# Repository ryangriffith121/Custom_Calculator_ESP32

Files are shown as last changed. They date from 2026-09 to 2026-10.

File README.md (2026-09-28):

# Custom Calculator ESP32

A custom calculator project built around an ESP32 microcontroller and a 4-inch ST7796S TFT display. The PCB and schematic have been developed in KiCad, and the next phase is generating Gerber files for manufacturing, followed by enclosure design and firmware development.

## 🎯 Project Goal

Create a compact, custom 4-function calculator with:

- Addition
- Subtraction
- Multiplication
- Division

The design combines a tactile keypad matrix, a high-visibility graphics display, and a lightweight ESP32-based control system.

## 🧩 Hardware Overview

### Core controller
- ESP32 development module / ESP32-WROOM-style board footprint
- Connected to the keypad matrix and display interface
- Planned for calculation logic, UI rendering, and input handling

### Display
- 4-inch TFT display
- ST7796S controller
- Intended for calculator UI, numeric input, operator selection, and result display

### Input device
- Tactile switch matrix arranged in a key layout
- Supports numeric keys and operator keys
- Wiring is organized in a row/column matrix for efficient GPIO usage

### Power and support
- 3.3V logic rail
- Test points for power, reset, SPI, and signal debug
- ESP32 GPIOs mapped for display and keypad interfacing

## ✅ Current Status

### Completed
- PCB design completed in KiCad
- Schematic capture completed in KiCad
- Gerber files generated and ready for manufacturing
- Device planning for ESP32 + display + keypad matrix
- GPIO and pin allocation for the external interfaces
- Basic project structure in the workspace

Schematic:


PCB Layout and Wiring:



PCB Rendering:



### Remaining work
- Enclosure design and mechanical fit for the display, buttons, and assembly
- Firmware programming for keypad scanning, display output, and calculator logic
- Final validation and hardware bring-up

## 📁 Repository Structure

```text
Custom_Calculator_ESP32/
├── CAD/
│   └── (mechanical / enclosure or enclosure-related files)
├── ECAD/
│   └── Calculator/
│       ├── Calculator.kicad_pro
│       ├── Calculator.kicad_sch
│       ├── Calculator.kicad_pcb
│       └── Calculator.kicad_prl
├── Programming/
│   └── (firmware source code and future development files)
├── README.md
└── .git/
```

## 📝 Design Notes

This project is intended to be a functional calculator rather than a general-purpose embedded display demo. The hardware is being designed around a straightforward architecture:

1. User presses keypad buttons.
2. ESP32 reads the matrix input.
3. Firmware interprets numeric and operator inputs.
4. Calculation result is rendered on the ST7796S display.

## 🚀 Planned Next Steps

- Design the enclosure to match the completed PCB and display layout
- Add silkscreen labeling and mechanical constraints
- Complete firmware programming for keypad scanning, display rendering, and calculator logic
- Validate the display graphics and UI flow on the physical hardware
- Finalize assembly and testing of the completed calculator

## 💻 Firmware Direction

The firmware can be implemented with:

- GPIO scanning for the keypad matrix
- SPI communication to the ST7796S TFT display
- Basic arithmetic state machine for calculator operation
- Keyboard debounce handling
- Result and expression rendering on screen

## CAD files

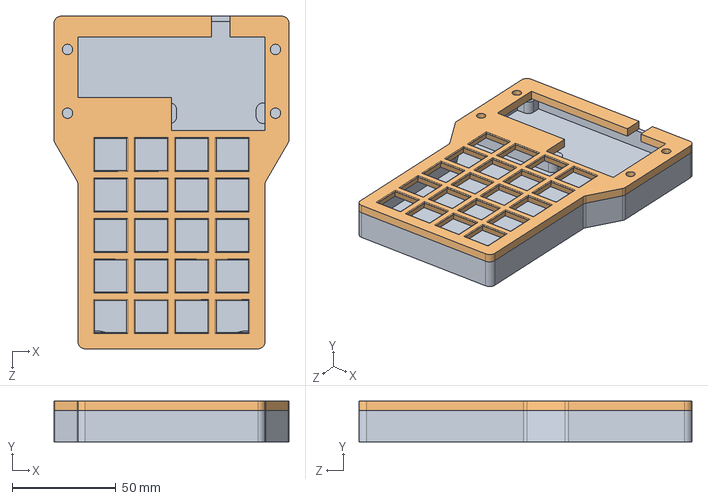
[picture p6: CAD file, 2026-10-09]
CAD/Calculator_Assem.STEP
113.0 x 19.5 x 160.0 mm
Calculator_Body_V2
Calculator_Plate

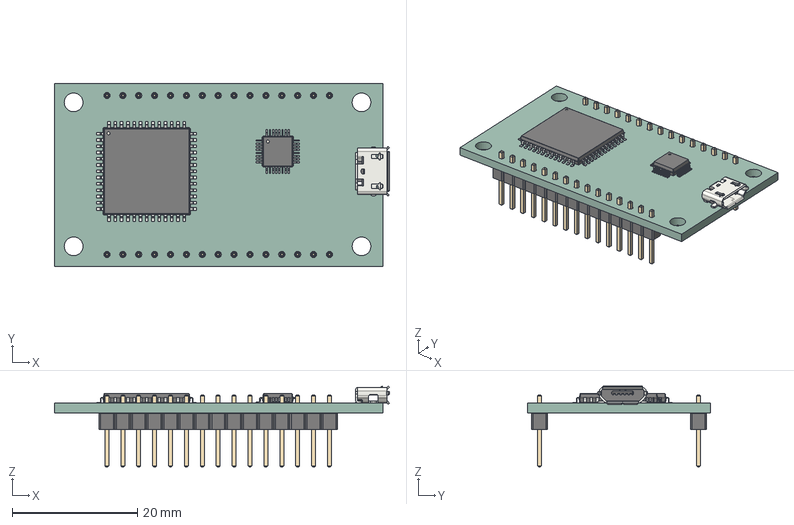
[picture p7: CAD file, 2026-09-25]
ECAD/Calculator/lib_models/ESP32-30pin.step
53.5 x 29.2 x 12.9 mm
LQFP_52_14x14mm_P1mm
USB_Micro-B_Molex_47346-0001
LQFP_32_5x5mm_P05mm
PinHeader_1x15_P254mm_Vertical x 2
ESP32-30pin PCB

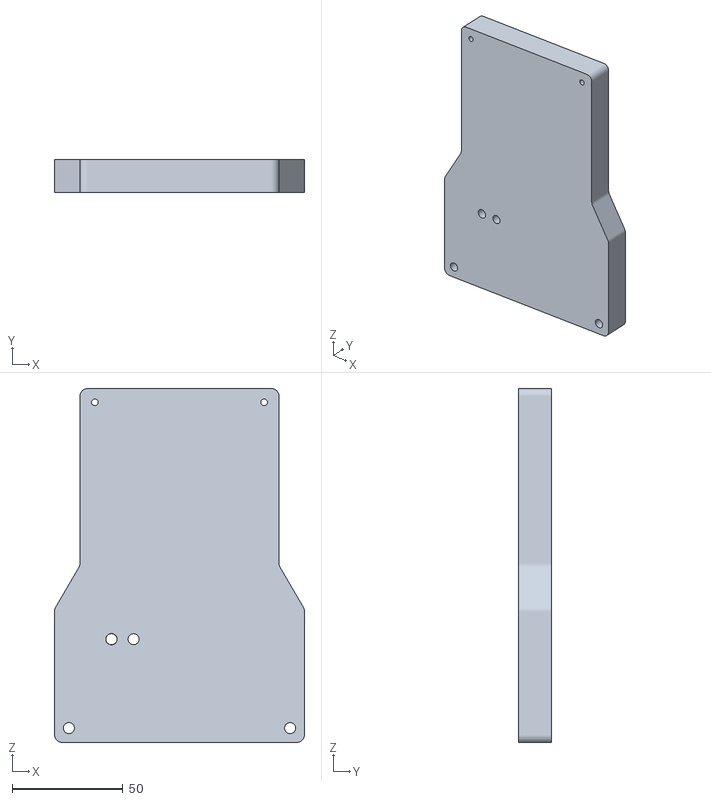
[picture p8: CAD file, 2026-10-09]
CAD/Calculator_Assem - Calculator_Body_V2-1.STL
113.0 x 15.0 x 160.0

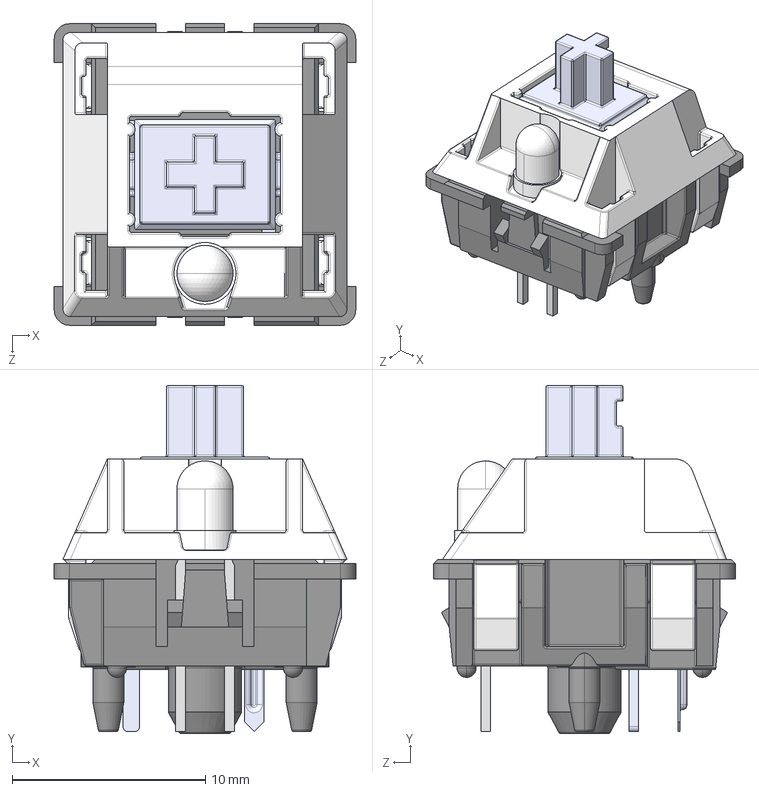
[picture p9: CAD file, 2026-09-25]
ECAD/Calculator/lib_models/Cherry MX.STEP
15.6 x 18.0 x 15.6 mm
Bottom
Pulsador
Top
Pieza5^Cherry MX
Pin1
Pin2
Led 3mm_trans

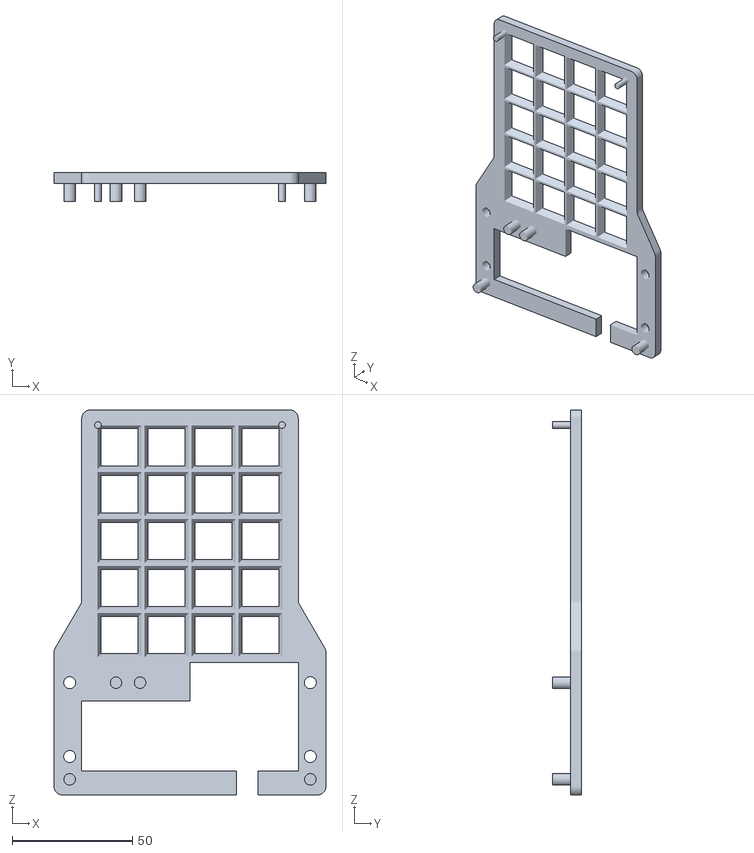
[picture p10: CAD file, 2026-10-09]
CAD/Calculator_Assem - Calculator_Plate-1.STL
113.0 x 12.0 x 160.0

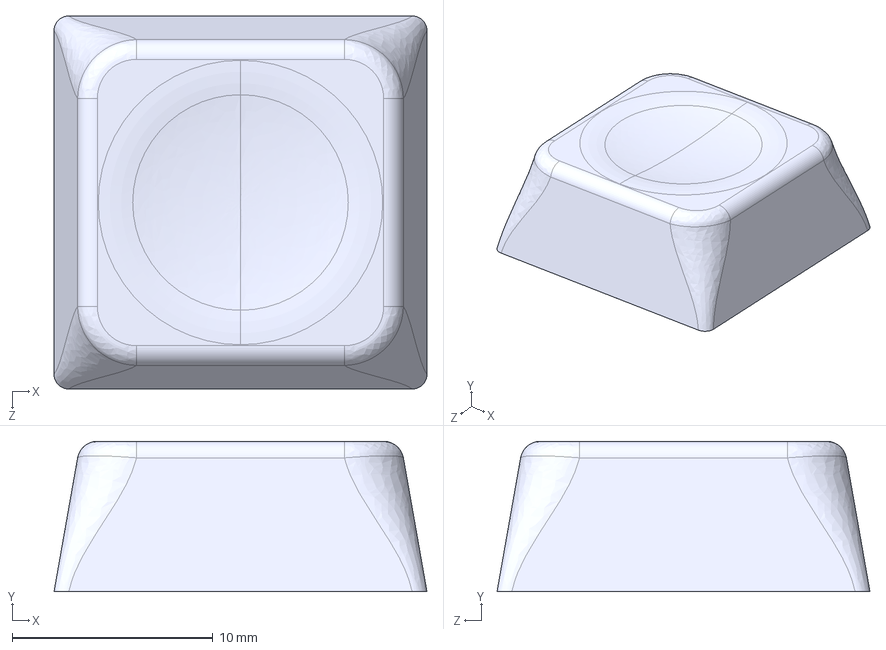
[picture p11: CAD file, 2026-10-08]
CAD/Stylized_Key_Cap_V2.STEP
18.6 x 7.50 x 18.6 mm

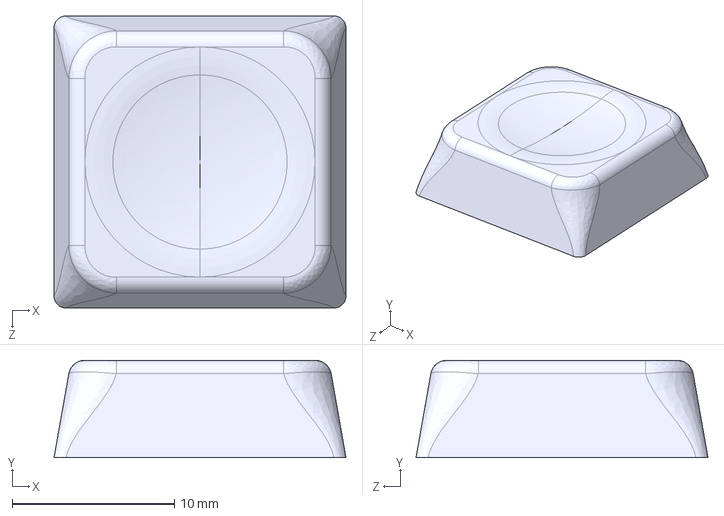
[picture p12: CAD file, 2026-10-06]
CAD/Stylized_Key_Cap_Concave.STEP
18.0 x 6.00 x 18.0 mm

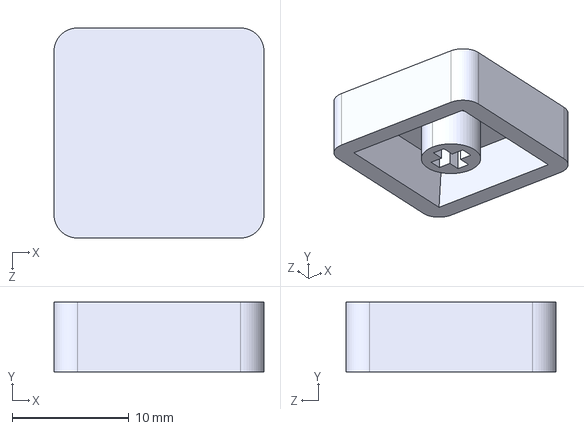
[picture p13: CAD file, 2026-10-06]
CAD/Basic_Key_Cap.STEP
18.0 x 6.00 x 18.0 mm

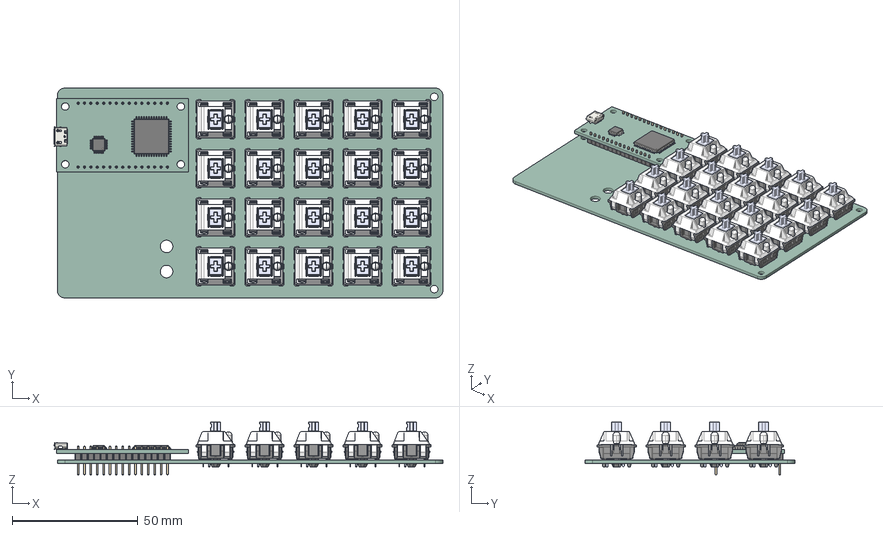
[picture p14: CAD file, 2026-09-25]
CAD/Calculator_PCB.step
154.8 x 83.5 x 21.1 mm
LQFP_52_14x14mm_P1mm
USB_Micro-B_Molex_47346-0001
LQFP_32_5x5mm_P05mm
PinHeader_1x15_P254mm_Vertical x 2
ESP32-30pin PCB
Bottom x 20
Pulsador x 20
Top x 20
Pieza5^Cherry MX x 20
Pin1 x 20
Pin2 x 20
Led 3mm_trans x 20
Calculator_PCB

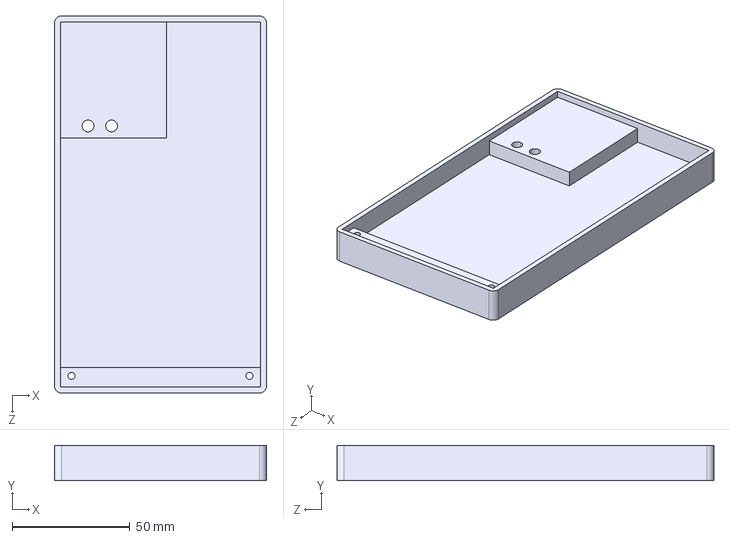
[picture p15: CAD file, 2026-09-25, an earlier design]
CAD/Calculator_Body_V1.STEP
90.0 x 15.0 x 160.0 mm

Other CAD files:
CAD/Calculator_Plate.STEP
CAD/Calculator_Body_V2.STEP
CAD/Stylized_Key_Cap_V2_Square_Stem.STEP
CAD/Stylized_Key_Cap_Flat.STEP
CAD/Basic_Key_Cap.SLDPRT
CAD/Basic_Key_Cap.STL
CAD/Calculator_Assem.SLDASM
CAD/Calculator_Body_V1.SLDPRT
CAD/Calculator_Body_V1.STL
CAD/Calculator_Body_V2.SLDPRT
CAD/Calculator_Body_V2.STL
CAD/Calculator_PCB.SLDASM
CAD/Calculator_Plate.SLDPRT
CAD/Calculator_Plate.STL
CAD/Stylized_Key_Cap_Concave.SLDPRT
CAD/Stylized_Key_Cap_Concave.STL
CAD/Stylized_Key_Cap_Flat.SLDPRT
CAD/Stylized_Key_Cap_Flat.STL
CAD/Stylized_Key_Cap_V2.SLDPRT
CAD/Stylized_Key_Cap_V2.STL
CAD/Stylized_Key_Cap_V2_Square_Stem.SLDPRT
CAD/Stylized_Key_Cap_V2_Square_Stem.STL

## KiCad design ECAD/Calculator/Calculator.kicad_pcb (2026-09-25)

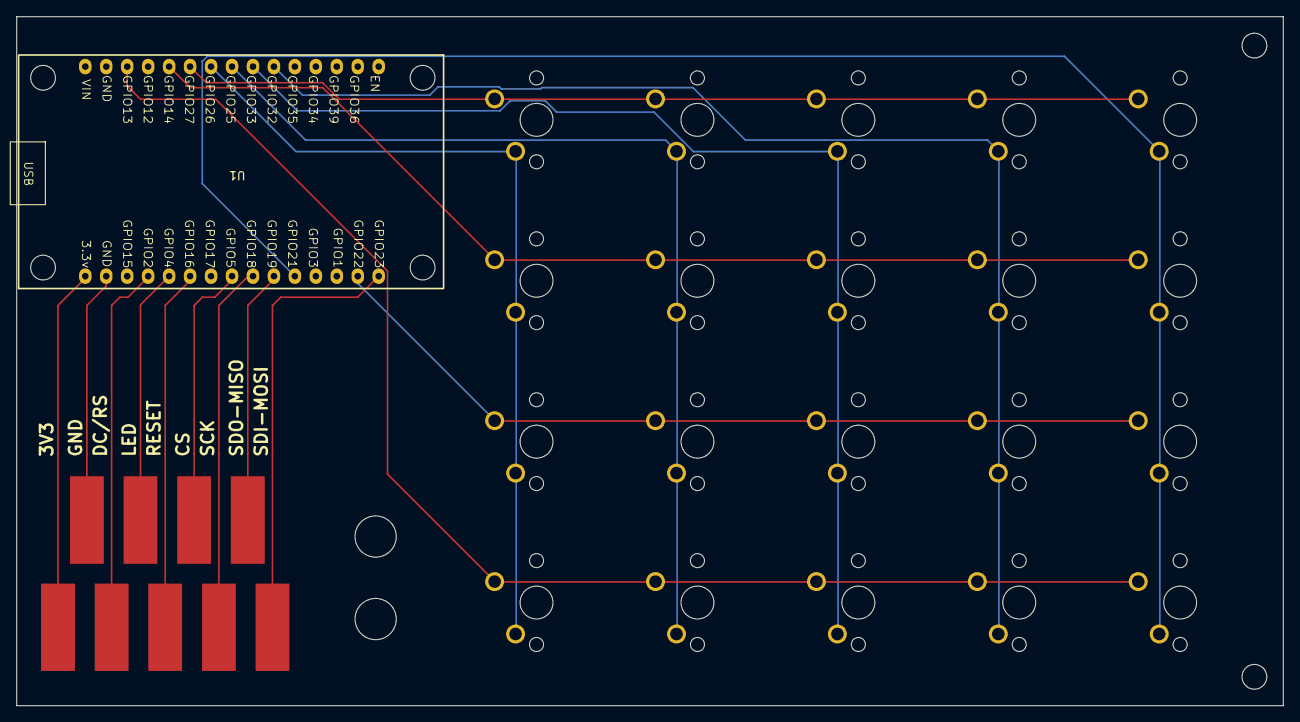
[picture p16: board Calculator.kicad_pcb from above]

Board: 2 copper layers, 153.5 x 83.5 mm, 30 parts (0 on the bottom side), 9 nets.

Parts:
SW1, SW2, SW3, SW4, SW5, SW6, SW7, SW8, SW9, SW10, SW11, SW12, SW13, SW14, SW15, SW16, SW17, SW18, SW19, SW20: Switch_Tactile_ESwitch; MX-Solderable-1U
TP1, TP2, TP3, TP4, TP5, TP6, TP7, TP8, TP9: TestPoint; Solder_pad
U1: ESP32_30pin

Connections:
/Col 1: SW1.2, SW2.2, SW3.2, SW4.2, SW5.2, U1.3 (GPIO13)
/Col 2: SW6.2, SW7.2, SW8.2, SW9.2, SW10.2, U1.29 (GPIO22)
/Col 3: SW11.2, SW12.2, SW13.2, SW14.2, SW15.2, U1.5 (GPIO14)
/Col 4: SW16.2, SW17.2, SW18.2, SW19.2, SW20.2, U1.6 (GPIO27)
/Row A: SW1.1, SW6.1, SW11.1, SW16.1, U1.7 (GPIO26)
/Row B: SW2.1, SW7.1, SW12.1, SW17.1, U1.8 (GPIO25)
/Row C: SW3.1, SW8.1, SW13.1, SW18.1, U1.9 (GPIO33)
/Row D: SW4.1, SW9.1, SW14.1, SW19.1, U1.10 (GPIO32)
/Row E: SW5.1, SW10.1, SW15.1, SW20.1, U1.26 (GPIO21)

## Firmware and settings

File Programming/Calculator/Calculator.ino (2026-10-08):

#include <TFT_eSPI.h>
TFT_eSPI tft;

const uint8_t ROW_PINS[] = {26, 25, 33, 32, 21};
const uint8_t COL_PINS[] = {13, 22, 14, 27};

constexpr uint8_t NUM_ROWS = sizeof(ROW_PINS);
constexpr uint8_t NUM_COLS = sizeof(COL_PINS);

bool state[NUM_ROWS][NUM_COLS];
unsigned long lastChange[NUM_ROWS][NUM_COLS];


void setup() {
  tft.init();
  tft.setRotation(1);
  tft.fillScreen(TFT_RED);
  tft.setTextColor(TFT_WHITE, TFT_RED);
  Serial.begin(115200);
  for (uint8_t c = 0; c < NUM_COLS; c++) pinMode(COL_PINS[c], INPUT_PULLUP);
  for (uint8_t r = 0; r < NUM_ROWS; r++) pinMode(ROW_PINS[r], INPUT);
  Serial.println("Key tester ready");
}

void loop() {
  for (uint8_t r = 0; r < NUM_ROWS; r++) {
    pinMode(ROW_PINS[r], OUTPUT);
    digitalWrite(ROW_PINS[r], LOW);
    delayMicroseconds(50);
    for (uint8_t c = 0; c < NUM_COLS; c++) {
      bool pressed = (digitalRead(COL_PINS[c]) == LOW);
      if (pressed != state[r][c] && millis() - lastChange[r][c] > 10) {
        state[r][c] = pressed;
        lastChange[r][c] = millis();
        Serial.printf("Row %u, Col %u %s\n", r, c, pressed ? "pressed" : "released");
      }
    }
    pinMode(ROW_PINS[r], INPUT);
  }
}

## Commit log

2026-09-22 Added file structure and completed KiCad Schematic file
    [Calculator.kicad_pcb, Calculator.kicad_sch]
2026-09-22 Refactor Calculator schematic and library components
    - Added multiple no-connect points in the Calculator schematic for better layout management.
    - Updated the footprint properties for buttons to use "Button_Switch_Keyboard:SW_Cherry_MX_1.00u_PCB" instead of the previous "PCM_fab:Button_ESwitch_TL3315NF100Q_4.5x4.5mm".
    - Introduced a new footprint for solder pads in the Calculator library.
    - Created a new footprint library table for the Calculator project.
    [Calculator.kicad_pcb, Calculator.kicad_sch]
2026-09-22 Completed layout for footprints for PCB
    [Calculator.kicad_pcb]
2026-09-22 Update PCB layout and added vias across the PCB
    [Calculator.kicad_pcb]
2026-09-23 Connect PCB pads to ESP32 and refined form factor
    [Calculator.kicad_pcb]
2026-09-23 Fixed switch placement
    [Calculator.kicad_pcb]
2026-09-23 Refactor schematic: Remove unnecessary wires and update connections in Calculator.kicad_sch Added keyboard matrix wiring in PCB and mounting holes for enclosure
    [Calculator.kicad_pcb, Calculator.kicad_sch]
2026-09-23 Update README.md: Revise project description and current status, including PCB design and Gerber file generation
2026-09-23 Update README with schematic and PCB layout
    Added schematic and PCB layout images to README.
2026-09-24 Added silkscreen notations to PCB, as well as logo and designation.
    [Calculator.kicad_pcb]
2026-09-24 Changed Various GPIO pins to avoid issures with missing pull-up resistors, and flash pins
    [Calculator.kicad_pcb, Calculator.kicad_sch]
2026-09-25 Add new footprint and symbol for ESP32 30-pin module
    - Created a new footprint file for the MX-Solderable-1U component, defining its dimensions and pad layout.
    - Added a new symbol library for the ESP32 30-pin module, including detailed pin configurations and properties for reference, value, footprint, and datasheet.
    - Added solidworks body prototype file for calculator.
    [Calculator_Body_V1.SLDPRT, Calculator_Body_V1.STEP, Calculator_Body_V1.STL]
2026-09-25 Update ESP32_30pin footprint and add new MX-Solderable-1U footprint
    - Updated ESP32_30pin.kicad_mod with new version, generator version, and 3D model
    - Added new MX-Solderable-1U.kicad_mod footprint with detailed properties and pads.
    - Introduced new 3D models for ESP32-30pin and Cherry MX switches.
    [Calculator.kicad_pcb, Calculator.kicad_sch, Calculator_Body_V1.SLDPRT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]
2026-09-25 Add Gerber files for Calculator project
    [Calculator-B_Cu.gbr, Calculator-B_Mask.gbr, Calculator-B_Paste.gbr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]
2026-09-25 Update README.md with enhanced section titles and current project status
2026-09-25 Add PCB rendering section to README
    Added PCB rendering image to the documentation.
2026-09-28 Update active layer in PCB settings and remove lock files
2026-09-29 Added TFT Library
    [Configuring options.txt]
2026-10-06 Added Keycap 3D files
    [Basic_Key_Cap.SLDPRT, Basic_Key_Cap.STEP, Basic_Key_Cap.STL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]
2026-10-07 Testing driver for ESP32 and ST7796 Screen
2026-10-08 Added two new keycap types
    [Stylized_Key_Cap_V2.SLDPRT, Stylized_Key_Cap_V2_Square_Stem.SLDPRT]
2026-10-08 Added STEP and STL files
    [Stylized_Key_Cap_V2.STEP, Stylized_Key_Cap_V2.STL, Stylized_Key_Cap_V2_Square_Stem.STEP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]
2026-10-08 FIxed key GPIO pins
    [Calculator.ino]
2026-10-08 Created a new part file for the Calculator body (Calculator_Body_V2.SLDPRT)
    [Calculator_Body_V2.SLDPRT, Calculator_Body_V2.STEP, Calculator_Body_V2.STL]
2026-10-09 Added Calculator Assembly file and Top Plate file
    [Calculator_Assem.SLDASM, Calculator_Body_V2.SLDPRT, Calculator_Plate.SLDPRT]
2026-10-15 Added new plate and new body models
2026-10-23 Added Alcove STL
2026-10-23 Added Bezel part and STL
2026-10-27 Sorted CAD files into folders and added some STEP and STL files
2026-10-27 Updates Alcove and Bezel files, added STEP and STL
2026-11-01 Added STL for PCB
